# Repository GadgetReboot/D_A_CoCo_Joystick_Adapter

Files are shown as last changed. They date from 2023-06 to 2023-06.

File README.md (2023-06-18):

# D_A_CoCo_Joystick_Adapter
Tandy CoCo Joystick Adapter:  Digital to Analog Joystick Circuit
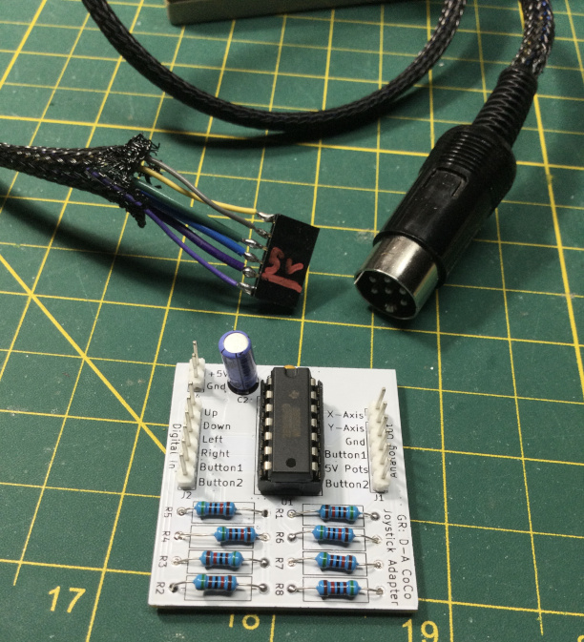
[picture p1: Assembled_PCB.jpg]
PCB
<br><br><br><br>
Use 5v/GND digital signals to control the analog joystick input of a Tandy Color Computer.<br>
When input buttons are not pressed, the joystick port sees approx. 5v / 2 = 2.5v, centering the joystick axis.
When a button is pressed, the joystick port sees 0V or 5V, representing the axis being at min or max of the analog range.

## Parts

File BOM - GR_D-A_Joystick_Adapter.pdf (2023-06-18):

CoCo Digital to Analog Joystick BOM

Item # | Reference Designator | Qty | Manufacturer | Mfg Part # | Description / Value | Package/Footprint | Type | Instructions / Notes
1 | C1 | 1 | KEMET | C320C104K5R5TA7317 | 0.1 µF ±10% 50V Ceramic Capacitor X7R Radial | 2.5mm Radial | THRU-HOLE
2 | C2 | 1 | Panasonic | ECA-1CM100I | 10 µF 16 V Aluminum Electrolytic Capacitor Radial | 2.5mm Pitch | THRU-HOLE
3 | J4 | 1 | Sullins | PREC002SAAN-RC | Connector Male Header Through Hole 2 position 0.100" | 2POS | THRU-HOLE
4 | J1 J2 | 2 | Sullins | PREC006SAAN-RC | Connector Male Header Through Hole 6 position 0.100" | 6POS | THRU-HOLE
5 | R1 R2 R3 R4 R5 R6 R7 R8 | 8 | YAGEO | CFR-25JR-52-47K | RES 47K OHM 5% 1/4W AXIAL | Axial | THRU-HOLE
6 | U1 | 1 | T.I. | CD4066BE | IC QUAD BILATERAL SWITCH 14DIP | DIP-14 | THRU-HOLE

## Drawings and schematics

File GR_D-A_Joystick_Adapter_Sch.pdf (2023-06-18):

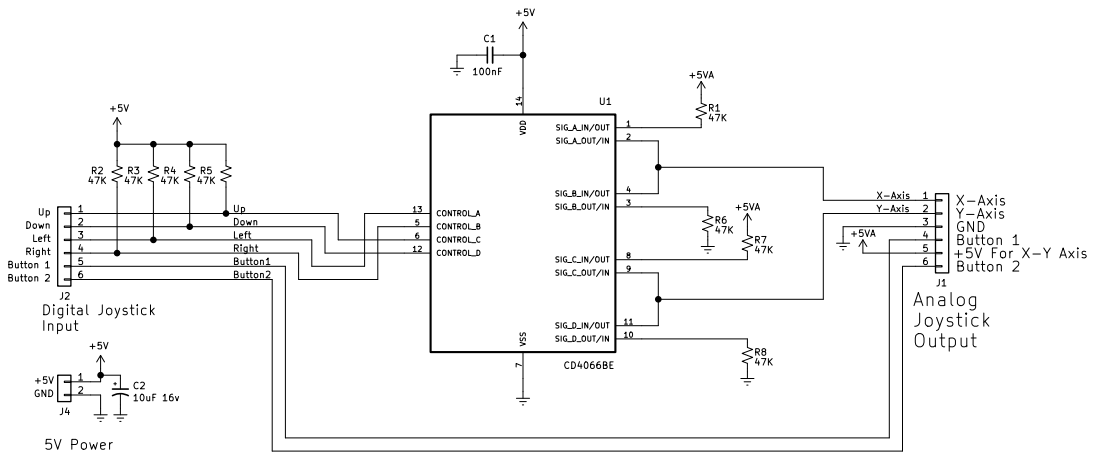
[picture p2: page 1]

https://github.com/GadgetReboot/D_A_CoCo_Joystick_Adapter
https://www.youtube.com/gadgetreboot
File: GR_D-A_Joystick_Adapter.sch Sheet: / Gadget Reboot

Id: 1/1 Title: Digital to Analog CoCo Joystick Adapter

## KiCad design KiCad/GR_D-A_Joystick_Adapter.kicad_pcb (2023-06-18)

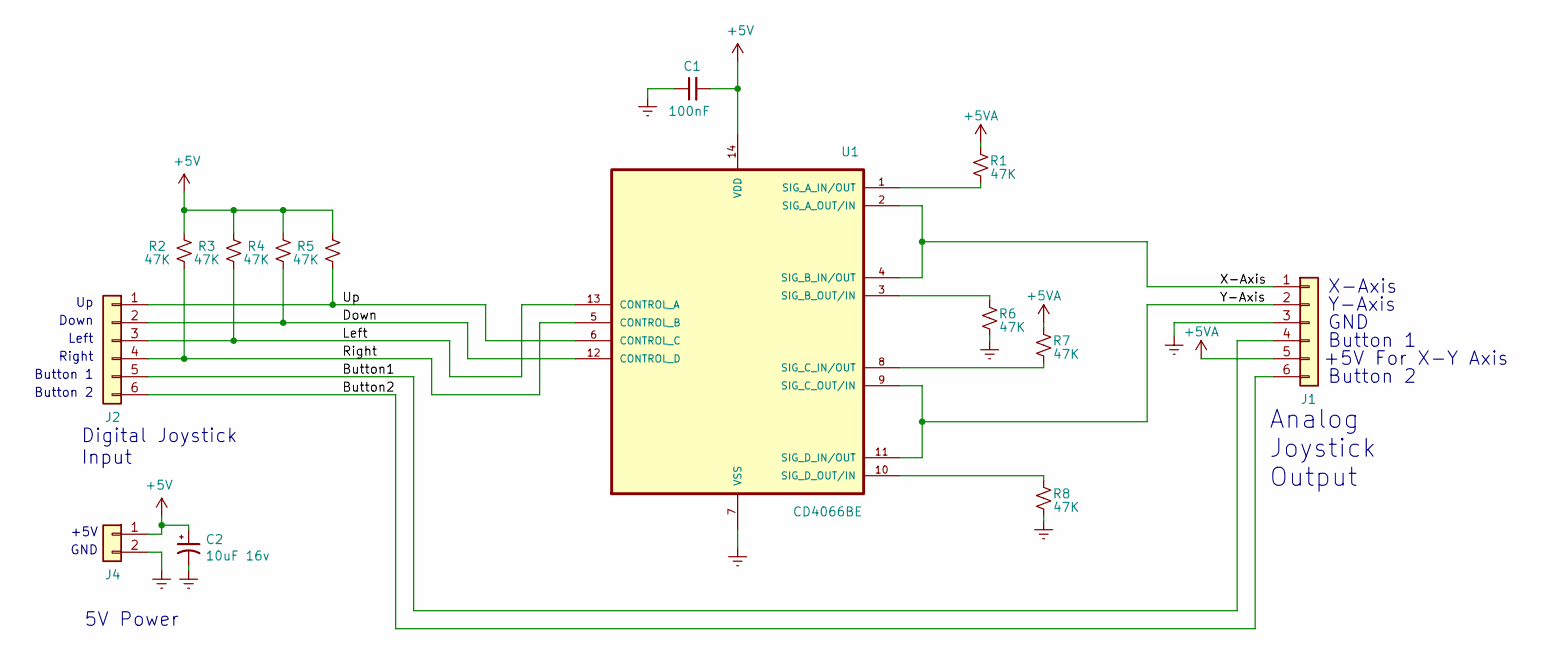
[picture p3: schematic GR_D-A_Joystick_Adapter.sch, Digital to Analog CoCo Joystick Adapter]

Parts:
C1: 100nF; C_Disc_D3.8mm_W2.6mm_P2.50mm
C2: 10uF 16v; CP_Radial_D5.0mm_P2.50mm
J1, J2: Conn_01x06; PinHeader_1x06_P2.54mm_Vertical
J4: Conn_01x02; PinHeader_1x02_P2.54mm_Vertical
R1, R2, R3, R4, R5, R6, R7, R8: 47K; R_Axial_DIN0309_L9.0mm_D3.2mm_P12.70mm_Horizontal
U1: CD4066BE; DIP-14_W7.62mm_Socket_LongPads

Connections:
+5V: C1.2, C2.1, J4.1, R2.1, R3.1, R4.1, R5.1, U1.14 (VDD)
+5VA: J1.5, R1.1, R7.1
/Button1: J1.4, J2.5
/Button2: J1.6, J2.6
/Down: J2.2, R4.2, U1.12 (CONTROL_D)
/Left: J2.3, R3.2, U1.13 (CONTROL_A)
/Right: J2.4, R2.2, U1.5 (CONTROL_B)
/Up: J2.1, R5.2, U1.6 (CONTROL_C)
/X-Axis: J1.1, U1.2 (SIG_A_OUT/IN), U1.4 (SIG_B_IN/OUT)
/Y-Axis: J1.2, U1.9 (SIG_C_OUT/IN), U1.11 (SIG_D_IN/OUT)
GNDREF: C1.1, C2.2, J1.3, J4.2, R6.2, R8.2, U1.7 (VSS)
unnamed: R1.2, U1.1 (SIG_A_IN/OUT)
unnamed: R6.1, U1.3 (SIG_B_OUT/IN)
unnamed: R7.2, U1.8 (SIG_C_IN/OUT)
unnamed: R8.1, U1.10 (SIG_D_OUT/IN)

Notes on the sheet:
5V Power
+5V
GND
Analog Joystick Output
X-Axis
Y-Axis
Button 1
+5V For X-Y Axis
Button 2
Digital Joystick Input
Button 2
Right
Left
Down

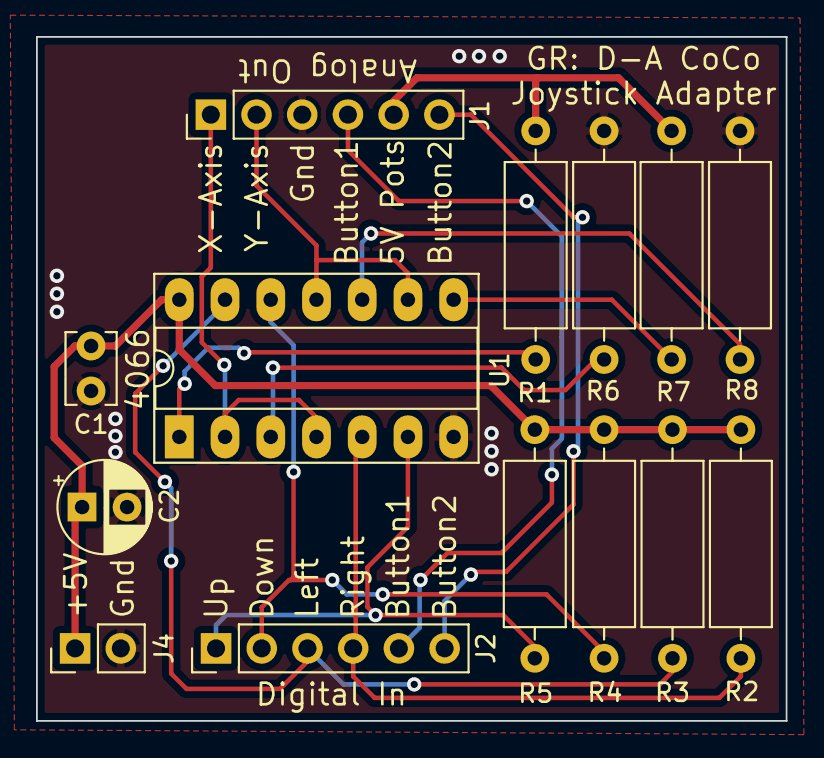
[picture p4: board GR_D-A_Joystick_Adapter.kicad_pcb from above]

Board: 2 copper layers, 41.7 x 38.0 mm, 14 parts (0 on the bottom side), 15 nets.
